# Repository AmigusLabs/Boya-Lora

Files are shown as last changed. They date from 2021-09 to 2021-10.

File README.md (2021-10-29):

# Boia-Lora
### Boia con alimentación solar, para telemetria de temperatura e altuara da ola do lago de As Pontes. Datos enviados por Lora para o seu procesado.

Ano 2021 - Proxecto financiado por Xunta de Galicia

A idea do proxecto é crear unha boia que nos permita coñecer o estado do lago, ben para goce da praia ou ben para os deportes que nel practícanse.

O obxectivo era crear un  instrumento económico e efectivo para xerar os datos, e en última instancia, mellorar a comprensicón deles. Este é o principal obxectivo do proxecto, deseño, rexistro e presentación dos datos.

Os sensores a bordo da boia permítenlle medir: altura das ondas, período das ondas, potencia das ondas, temperatura da auga, temperatura do aire, presión do aire, voltaxe e consumo actual e localización GPS.

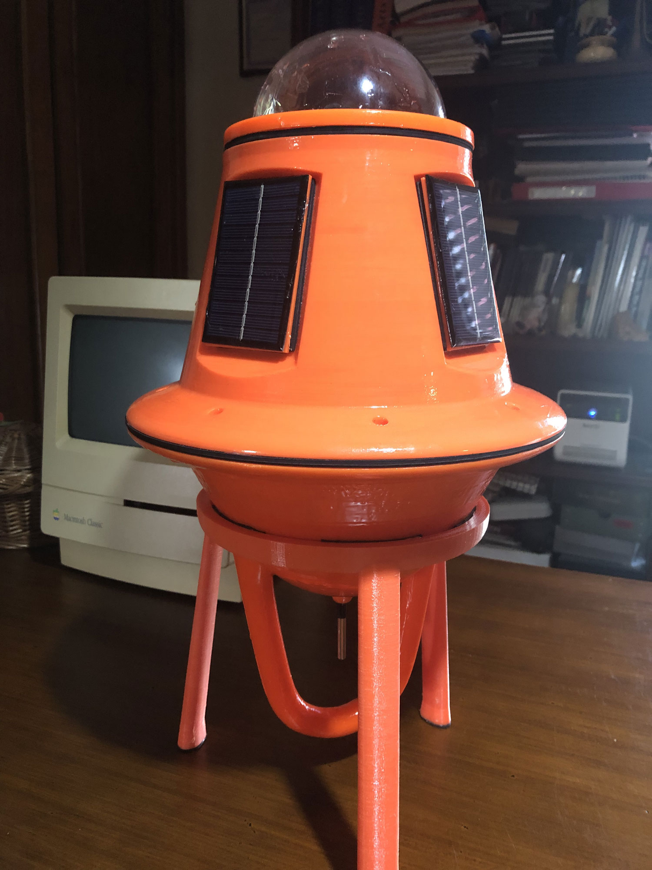
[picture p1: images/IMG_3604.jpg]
Boia lora


## Materiais

Para a construción completa da boia, necesita moitas cousas. Temos a desagregación dos materiais específicos requiridos en está a lista:

- Lilygo T-Beam 868mhzs
- 4 placas solares 90x60mm 6V 100mA
- INA219
- GY-86
- Sensor temperatura DS18B20
- Batería 18650
- PETG para impresión 3d
- GomaEVA
- Conectores PG7
- Regulador MT3608
- JMX-045 domo 4,5" / 114mm

## Estado:
- [ ] Desarrollo web (Rest API)
- [ ] Creación PCBs en KiCad para a electrónica
- [ ] Implementación Lora e envio a TTNv3
- [x] Implementación do software en T-BEAM de temperatua e sensores.
- [x] Implementación control enerxético
- [x] Fabricación 3d
- [x] Corte laser da Goma Eva
- [x] Deseño 2d
- [x] Deseño 3d

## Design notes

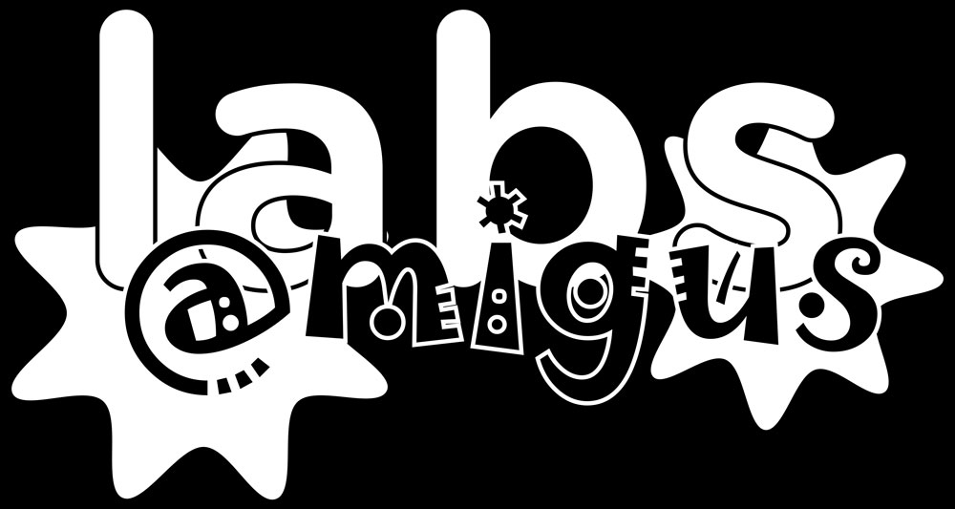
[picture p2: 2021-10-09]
Electronica/Electronica_Kicad_PowerSolar/amigus_labs.jpg

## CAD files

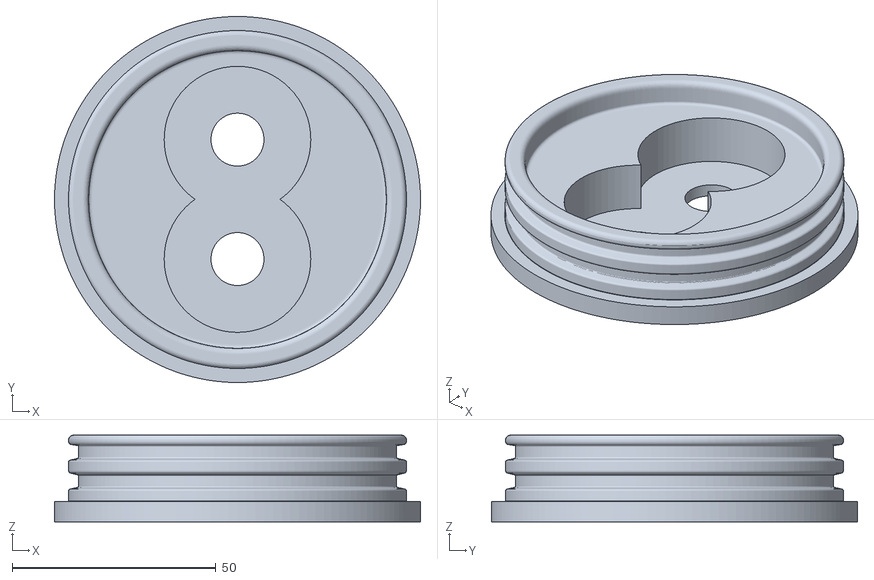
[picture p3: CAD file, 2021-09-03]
STL/tapa_capsula.stl
89.9 x 89.9 x 21.3

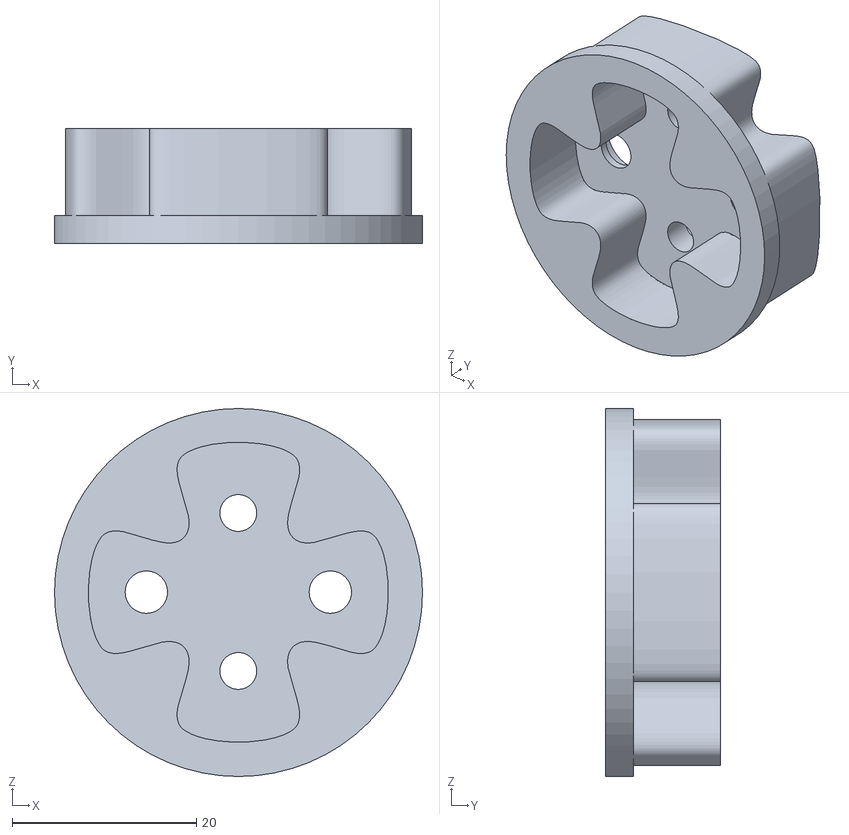
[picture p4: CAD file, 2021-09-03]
STL/soporte_placa_solar2a.stl
40.0 x 12.5 x 40.0

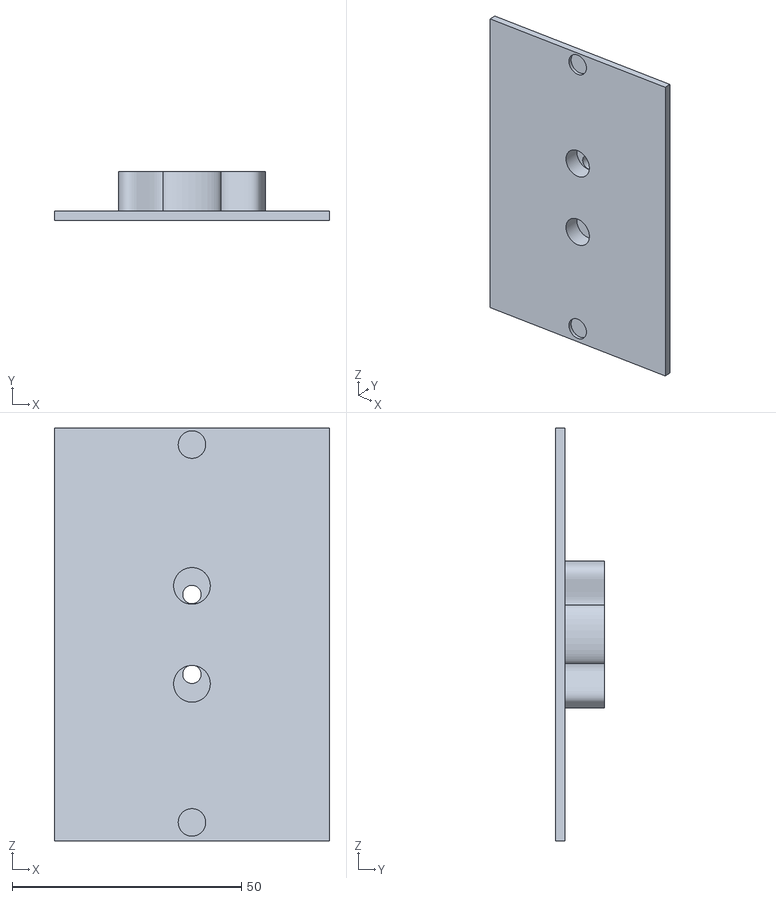
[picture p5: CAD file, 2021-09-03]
STL/soporte_placa_solar2.stl
60.0 x 10.6 x 90.0

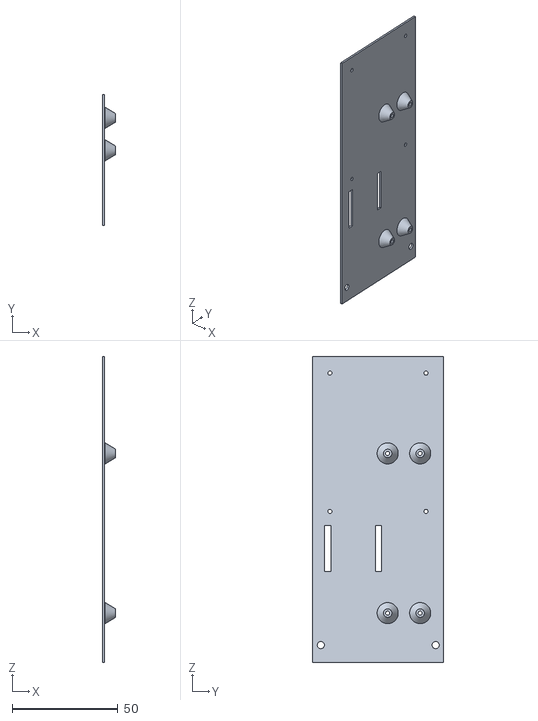
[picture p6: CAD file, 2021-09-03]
STL/soporte_PCBs1.stl
6.33 x 62.0 x 145.0

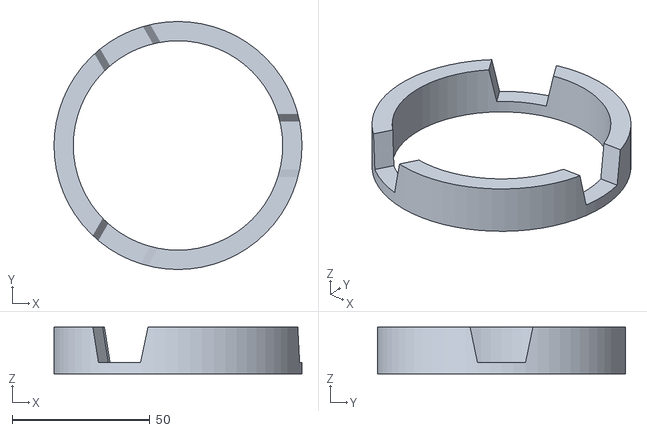
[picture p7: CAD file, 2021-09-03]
STL/soporte_capsula_17mmA.stl
90.0 x 90.0 x 17.0

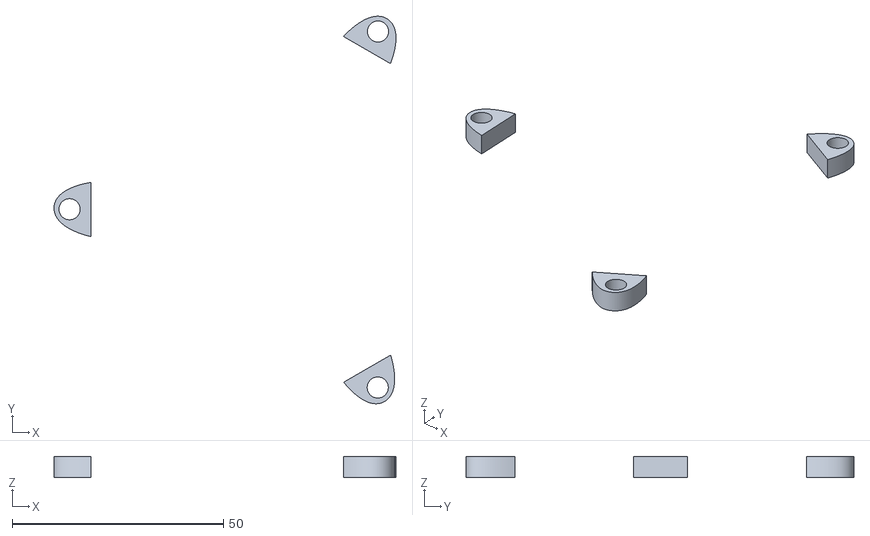
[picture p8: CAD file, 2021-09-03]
STL/tapa_capsula_add.stl
81.0 x 91.8 x 5.00

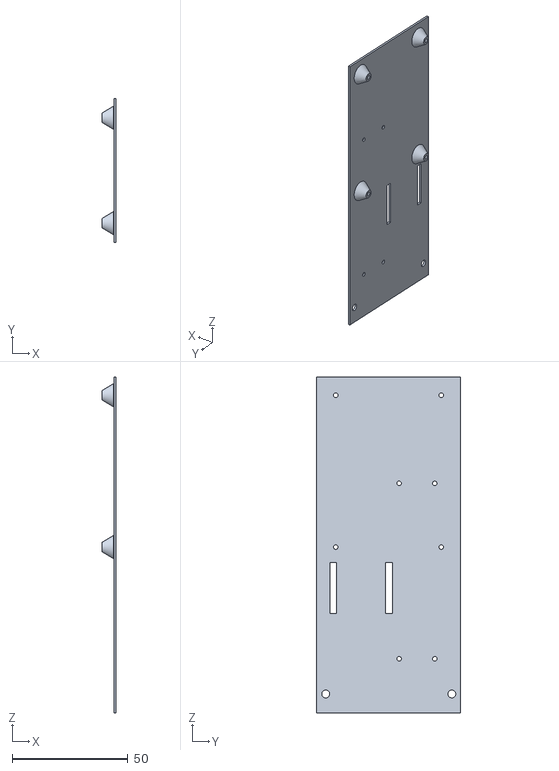
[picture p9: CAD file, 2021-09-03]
STL/soporte_PCBs2.stl
6.13 x 62.0 x 145.0

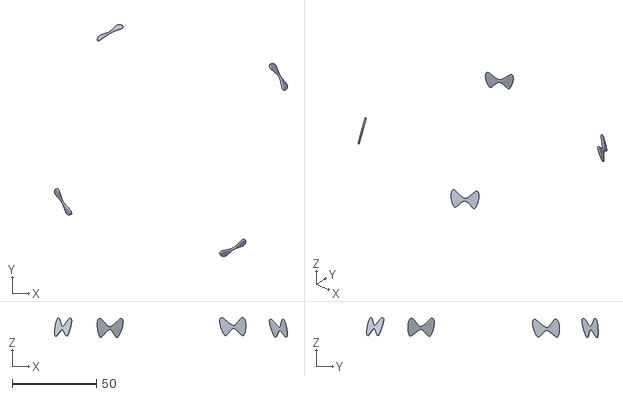
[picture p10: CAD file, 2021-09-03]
STL/Boya_arriba1_soportes.stl
138.6 x 137.9 x 12.0

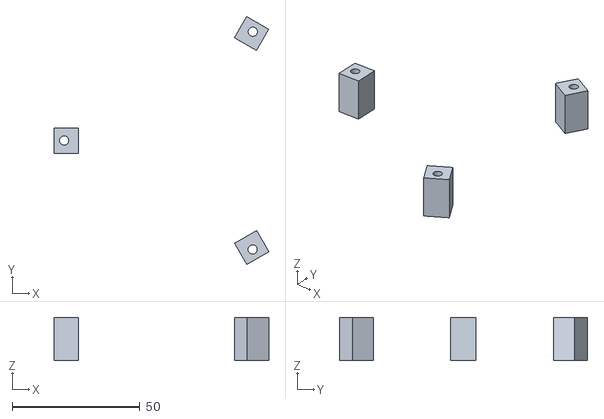
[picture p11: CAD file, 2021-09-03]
STL/soporte_capsula_17mmB.stl
84.1 x 97.1 x 17.0

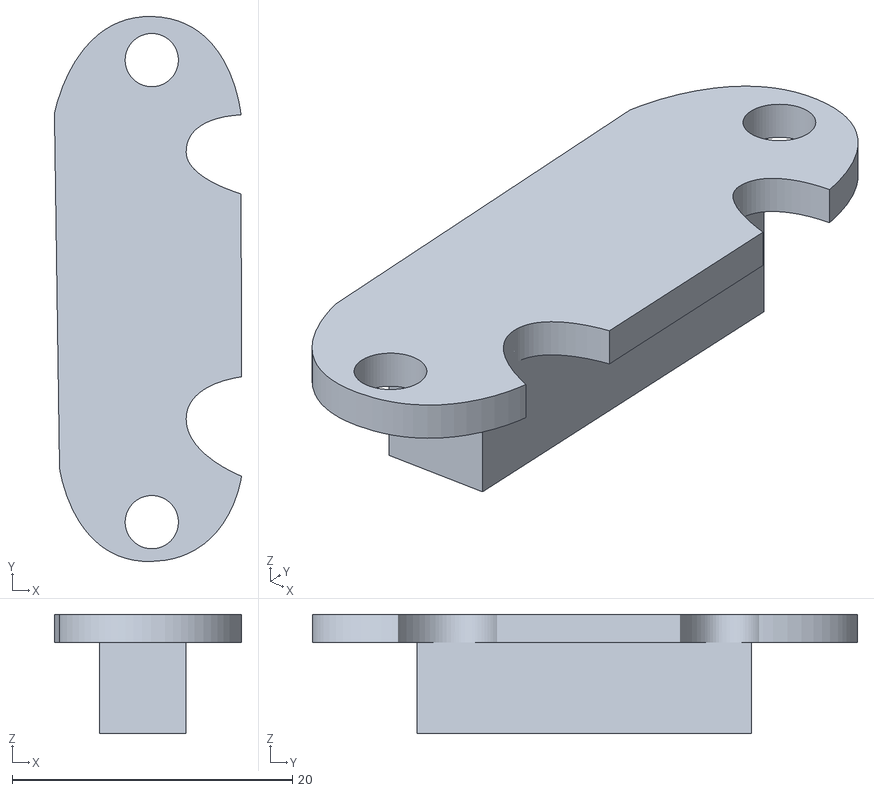
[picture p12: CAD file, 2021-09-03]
STL/Soporte_AntenaGPS.stl
13.4 x 38.9 x 8.51

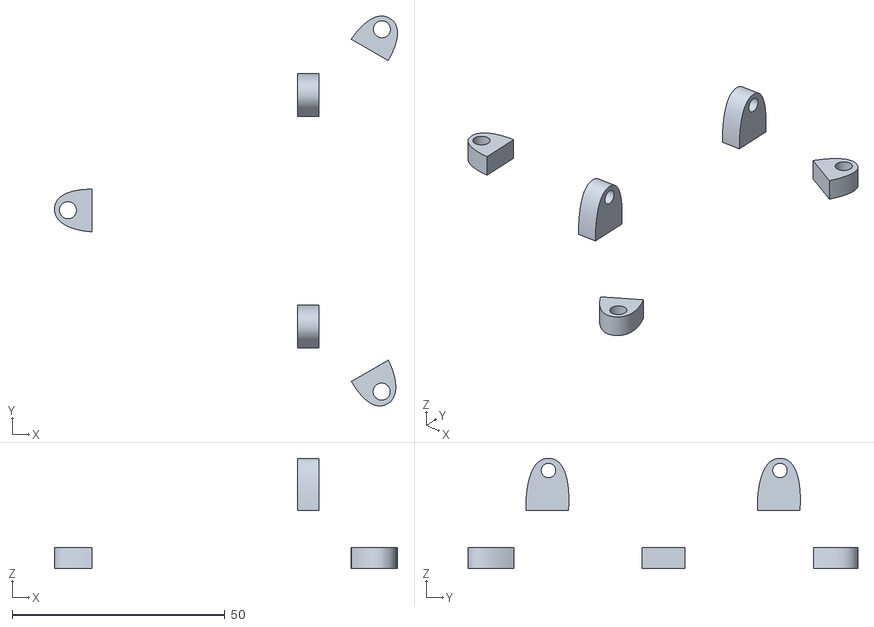
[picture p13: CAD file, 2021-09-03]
STL/tapa_capsula_superior_add.stl
80.7 x 91.7 x 26.0

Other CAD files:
STL/tapa_capsula_superior.stl

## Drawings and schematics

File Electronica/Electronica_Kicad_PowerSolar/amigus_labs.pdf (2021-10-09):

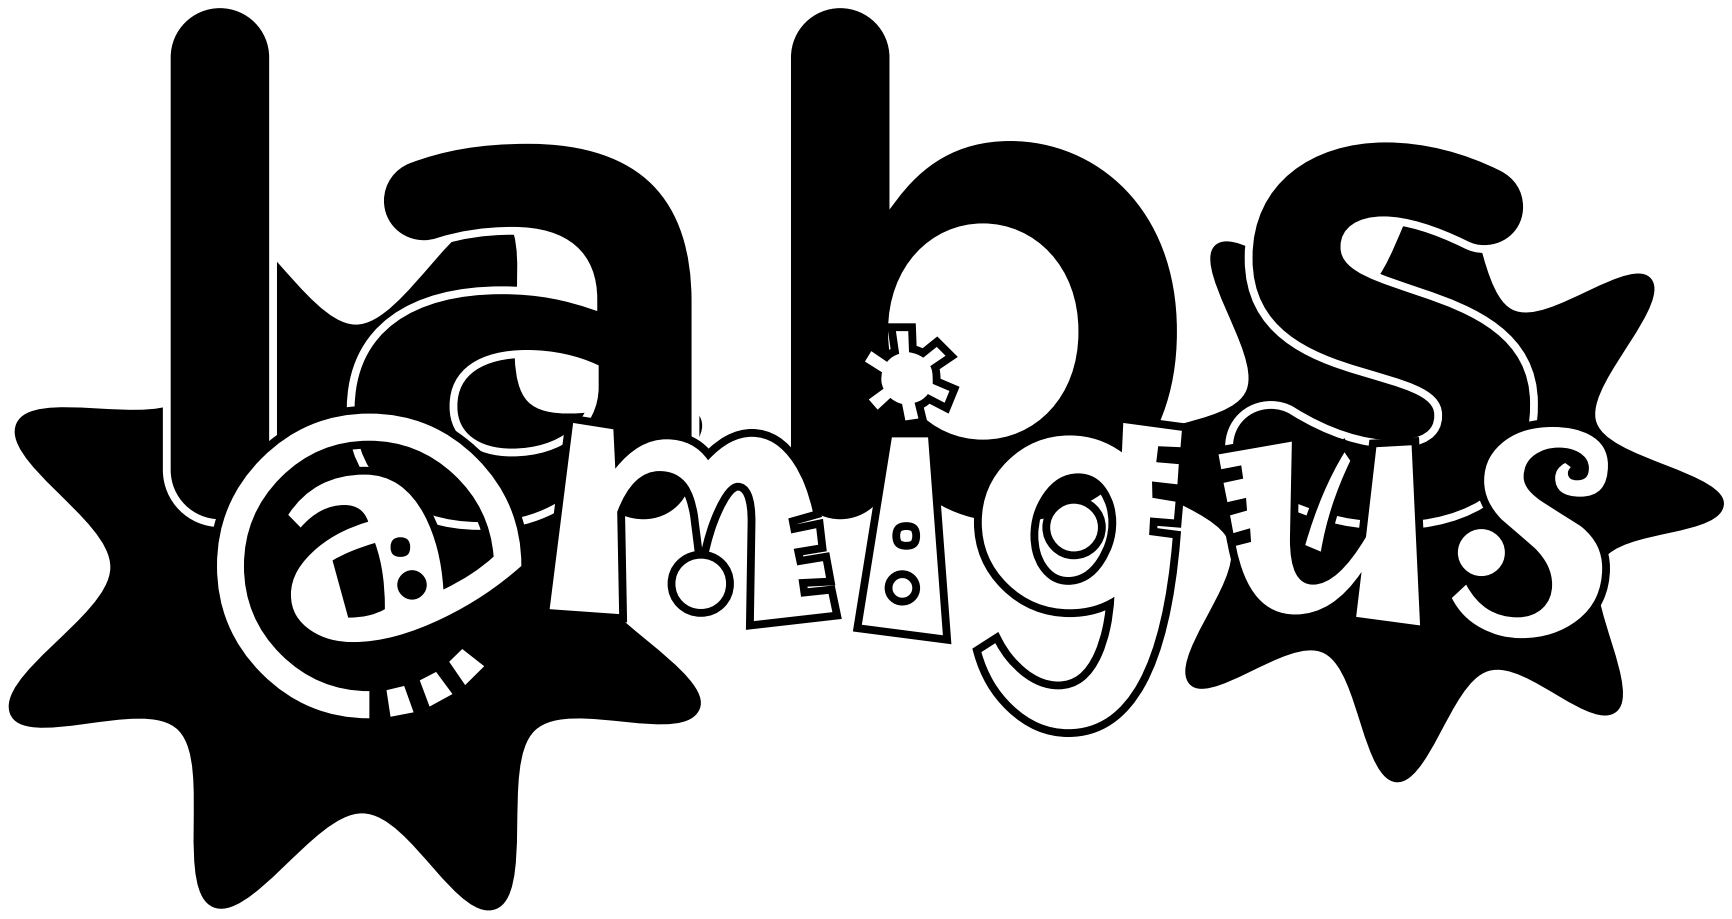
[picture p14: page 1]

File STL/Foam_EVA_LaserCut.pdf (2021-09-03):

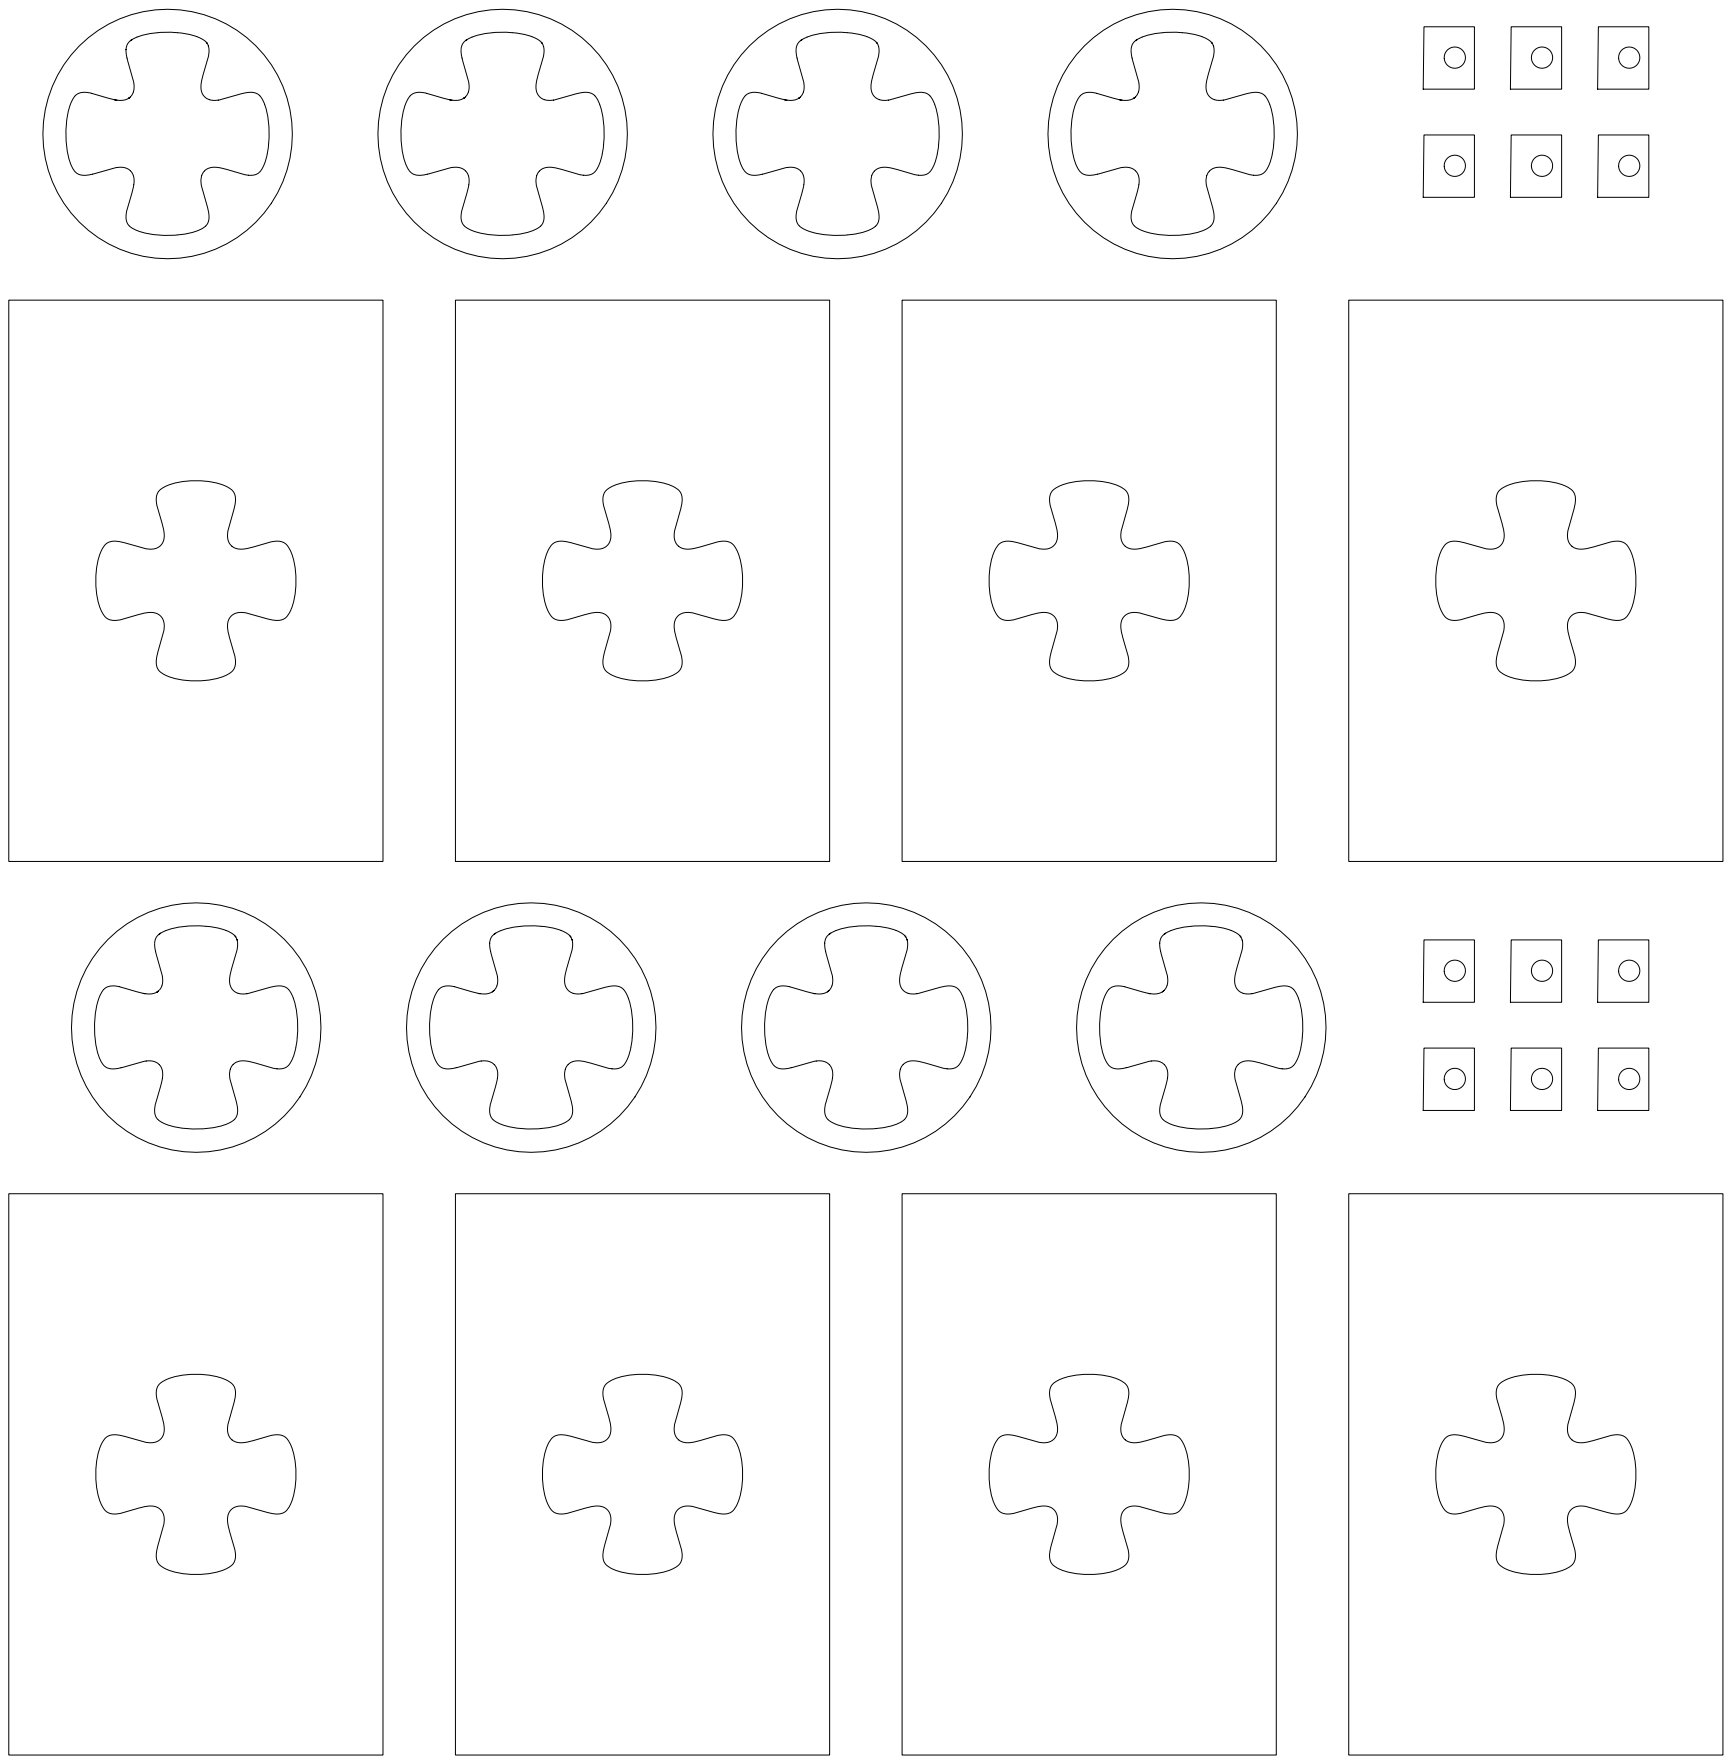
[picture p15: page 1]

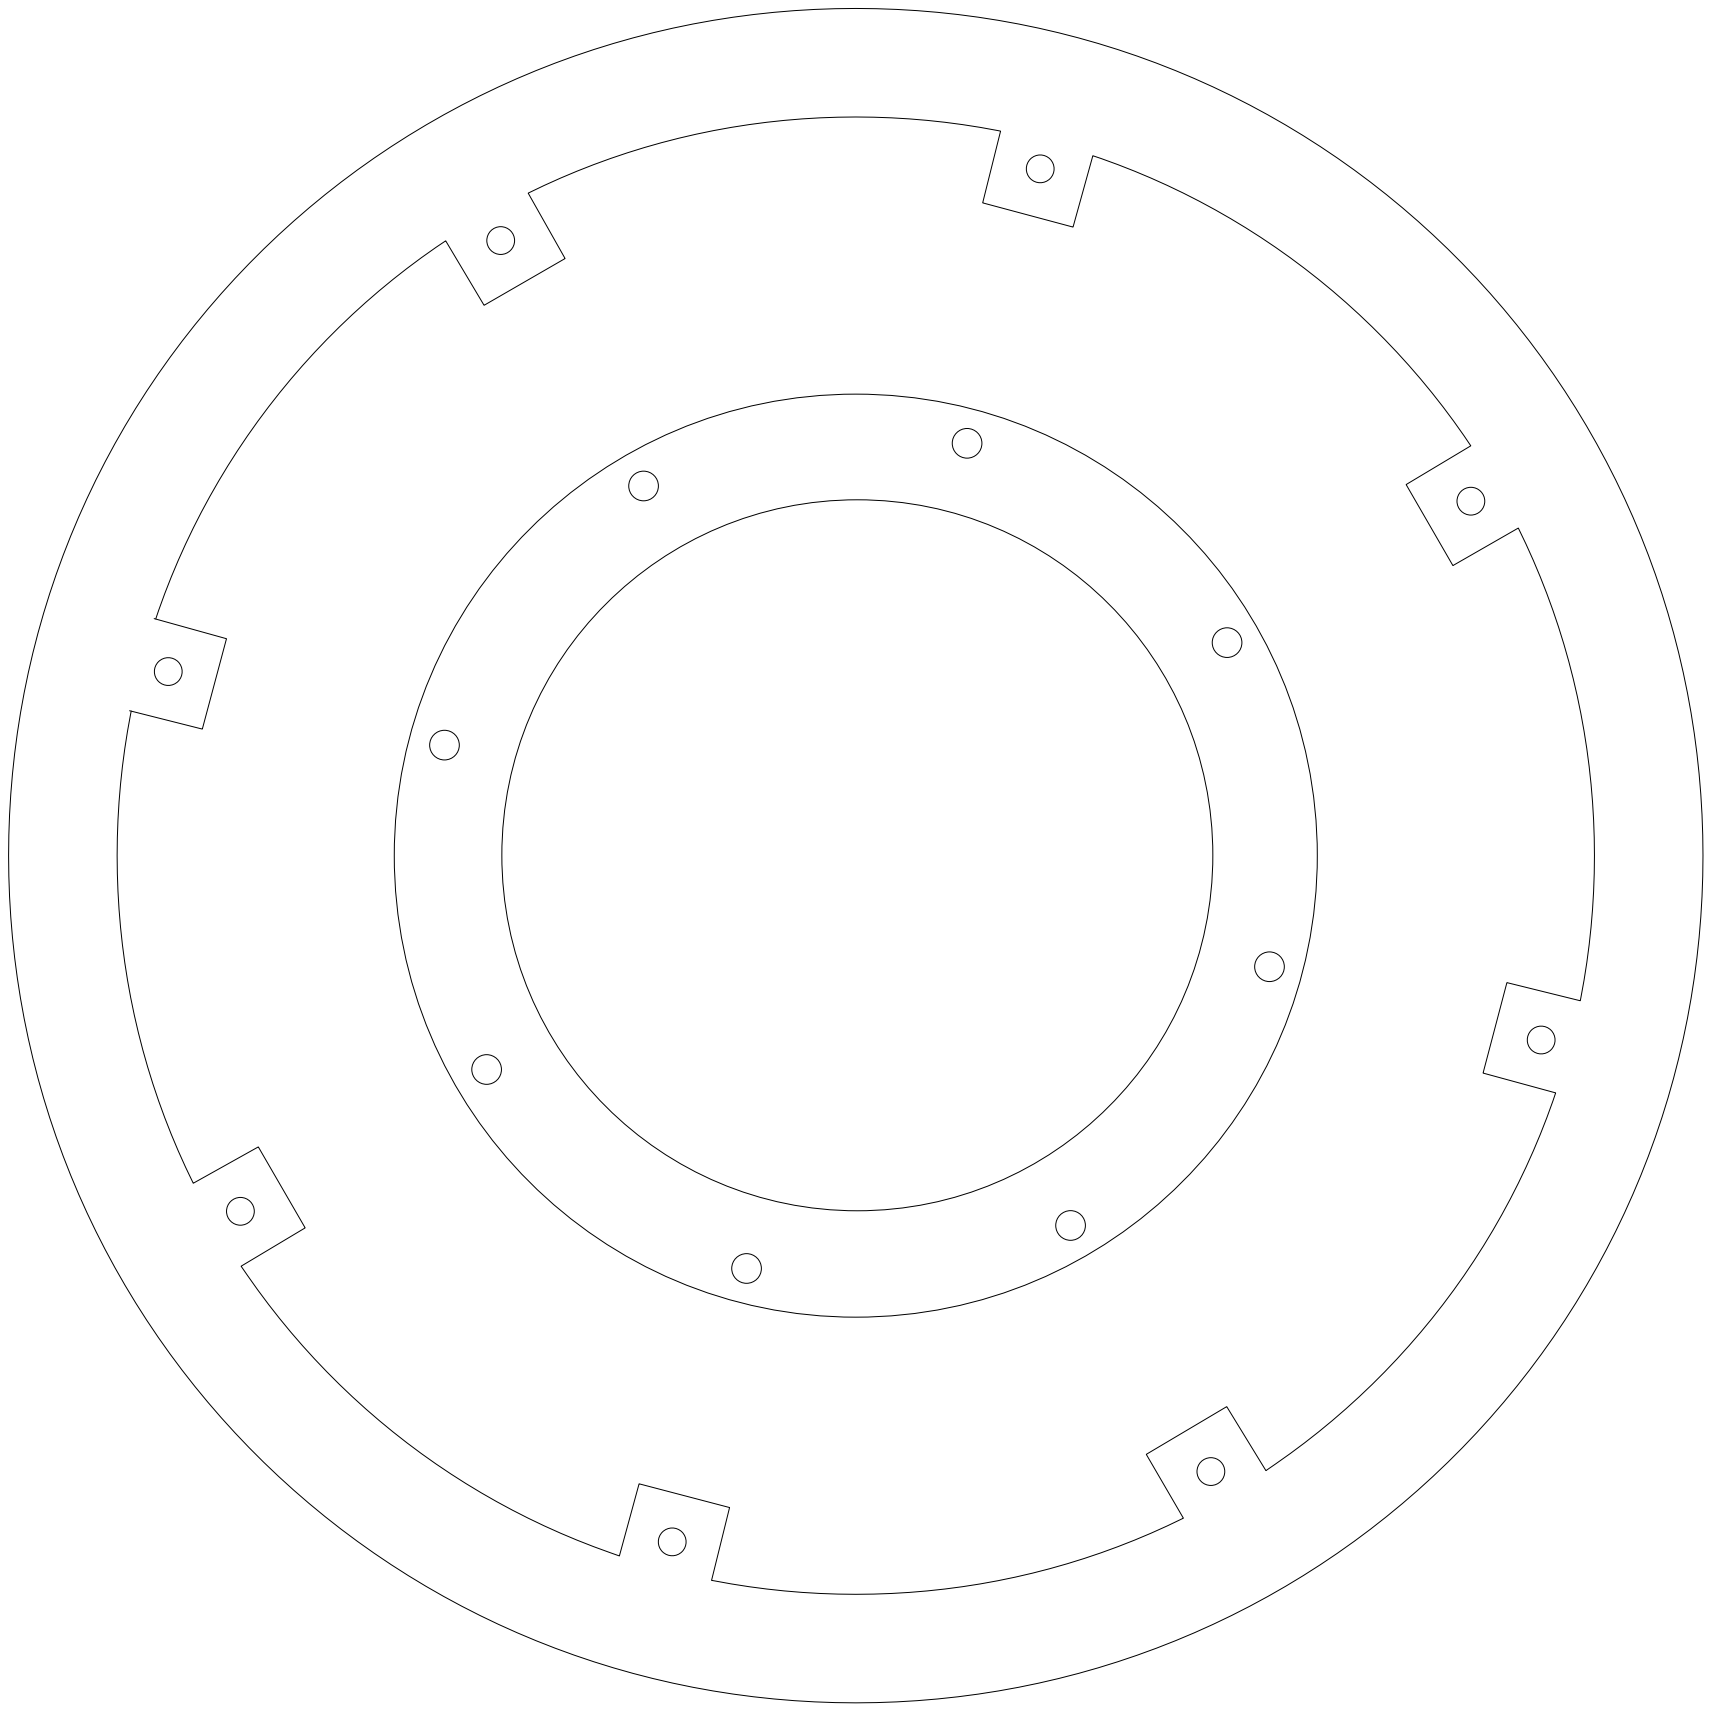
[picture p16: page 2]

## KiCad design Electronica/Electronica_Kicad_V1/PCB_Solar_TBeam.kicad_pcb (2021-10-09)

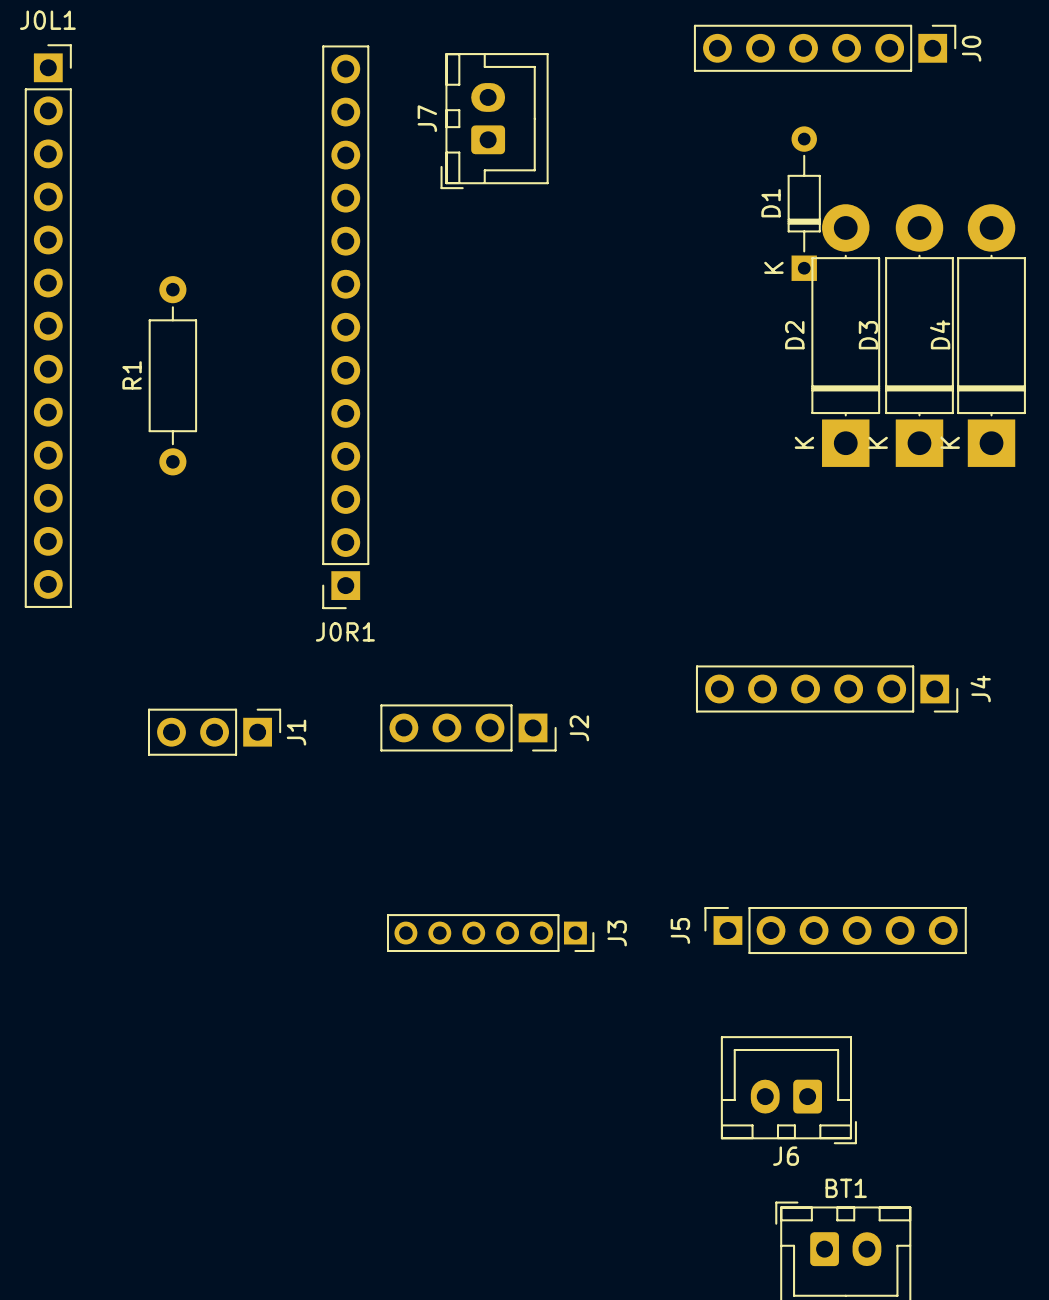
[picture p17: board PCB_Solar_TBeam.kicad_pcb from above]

Board: 2 copper layers, 16 parts (0 on the bottom side), 15 nets, no tracks yet.

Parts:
BT1: Battery; JST_XH_B2B-XH-A_1x02_P2.50mm_Vertical
D1: D; D_DO-34_SOD68_P7.62mm_Horizontal
D2, D3, D4: D; D_5W_P12.70mm_Horizontal
J0: IN Solar Power; PinHeader_1x06_P2.54mm_Vertical
J0L1: TTGO T-beam; PinSocket_1x13_P2.54mm_Vertical
J0R1: Conn_01x13_Female; PinSocket_1x13_P2.54mm_Vertical
J1: Termometro; PinHeader_1x03_P2.54mm_Vertical
J2: GY86; PinSocket_1x04_P2.54mm_Vertical
J3: INA219; PinSocket_1x06_P2.00mm_Vertical
J4, J5: Cargador 03962A; PinSocket_1x06_P2.54mm_Vertical
J6: INA219; JST_XH_B2B-XH-A_1x02_P2.50mm_Vertical
J7: Bat IN 5V; JST_XH_B2B-XH-A_1x02_P2.50mm_Vertical
R1: 4.7K; R_Axial_DIN0207_L6.3mm_D2.5mm_P10.16mm_Horizontal

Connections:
unnamed: BT1.1, J6.1
unnamed: BT1.2, J5.5
unnamed: D1.1, D2.1, D3.1, D4.1, J4.1
unnamed: D1.2, J0.4
unnamed: D2.2, J0.3
unnamed: D3.2, J0.2
unnamed: D4.2, J0.1
unnamed: J0.6, J4.6
unnamed: J0L1.3, J1.1, J2.4, J3.6, R1.2
unnamed: J0L1.4, J2.1, J3.3
unnamed: J0L1.5, J2.2, J3.4
unnamed: J0L1.10, J1.3, R1.1
unnamed: J0R1.12, J1.2, J2.3, J3.5, J7.1
unnamed: J0R1.13, J7.2
unnamed: J5.2, J6.2

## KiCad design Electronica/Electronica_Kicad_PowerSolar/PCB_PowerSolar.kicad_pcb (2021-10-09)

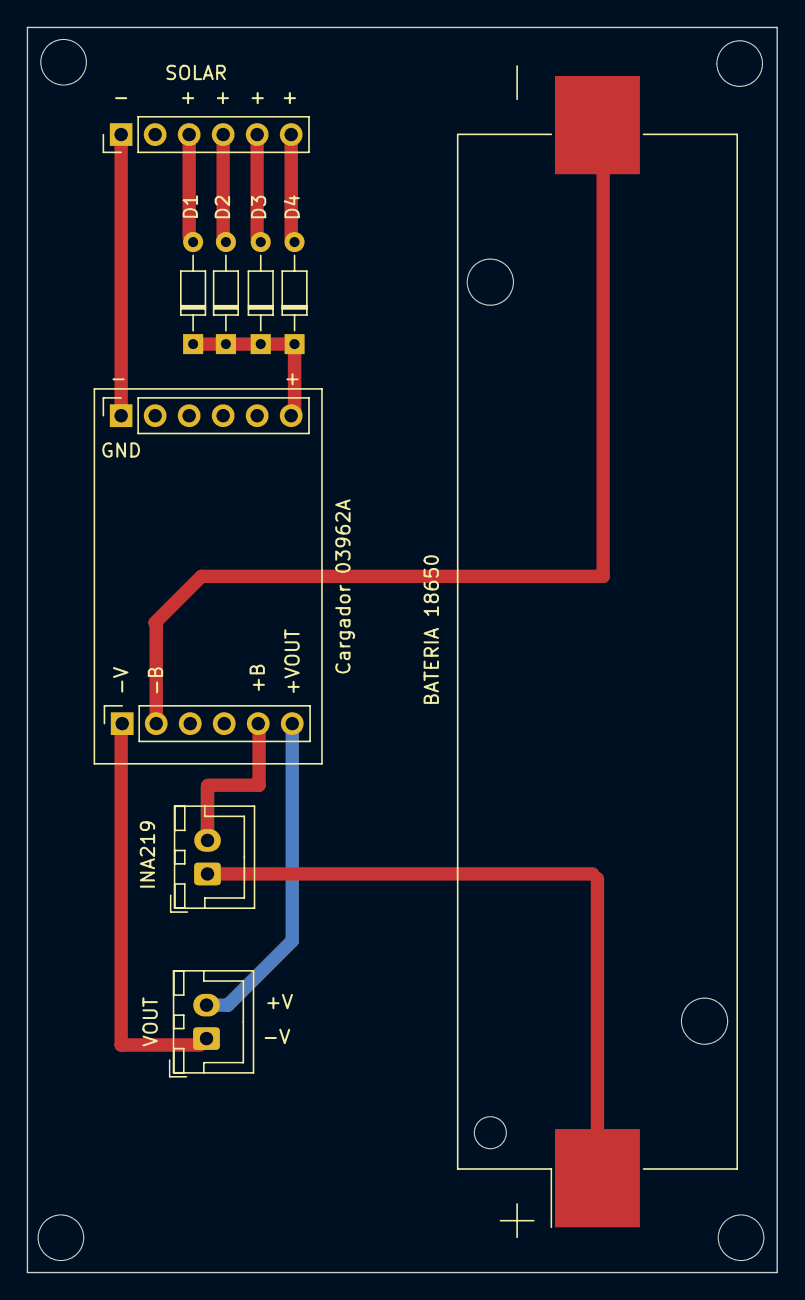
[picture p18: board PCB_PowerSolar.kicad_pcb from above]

Board: 2 copper layers, 56.0 x 93.0 mm, 10 parts (0 on the bottom side), 11 nets.

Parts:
BATERIA 18650: Battery; BatteryHolder_Keystone_1042_1x18650
D1, D2, D3, D4: D; D_DO-34_SOD68_P7.62mm_Horizontal
INA219: INA219; JST_XH_B2B-XH-A_1x02_P2.50mm_Vertical
J1, J2: Cargador 03962A; PinSocket_1x06_P2.54mm_Vertical
SOLAR: IN Solar Power; PinHeader_1x06_P2.54mm_Vertical
VOUT: V-OUT; JST_XH_B2B-XH-A_1x02_P2.50mm_Vertical

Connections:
unnamed: BATERIA 18650.1, INA219.1
unnamed: BATERIA 18650.2, J2.2
unnamed: D1.1, D2.1, D3.1, D4.1, J1.6
unnamed: D1.2, SOLAR.3
unnamed: D2.2, SOLAR.4
unnamed: D3.2, SOLAR.5
unnamed: D4.2, SOLAR.6
unnamed: J1.1, SOLAR.1
unnamed: J2.1, VOUT.1
unnamed: INA219.2, J2.5
unnamed: J2.6, VOUT.2

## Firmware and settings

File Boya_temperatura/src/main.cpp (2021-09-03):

#include <Arduino.h>
#include <OneWire.h>
#include <Wire.h>
#include <DallasTemperature.h>
#include "current.h" //INA219
#include <WiFi.h>
#include <esp_sleep.h>

#include <TinyGPS++.h>
#include <axp20x.h>
#include "I2Cdev.h"
#include "MPU6050.h"
#include <ms5611.h>

// GY86 -- Olas --
MPU6050 mpu;
MS5611 baro;
long pressure;
double altitude, min_height, max_height, wave_height, mid_point, smudge_factor, wave_power;
byte escaped, started;
unsigned long period_start, period_end;
float avg_period = -1;

// GPIO donde el DS18B20 está conectado
const int oneWireBus = 4;
OneWire oneWire(oneWireBus);
DallasTemperature sensors(&oneWire);

// GPS
TinyGPSPlus gps;
HardwareSerial GPS(1);
AXP20X_Class axp;

void setup()
{
  Serial.println("Iniciando");
  Serial.begin(115200);
  // GPS
  Wire.begin(21, 22);
  if (!axp.begin(Wire, AXP192_SLAVE_ADDRESS))
  {
    Serial.println("AXP192 Begin PASS");
  }
  else
  {
    Serial.println("AXP192 Begin FAIL");
  }
  axp.setPowerOutPut(AXP192_LDO2, AXP202_ON);
  axp.setPowerOutPut(AXP192_LDO3, AXP202_ON);
  axp.setPowerOutPut(AXP192_DCDC2, AXP202_ON);
  axp.setPowerOutPut(AXP192_EXTEN, AXP202_ON);
  axp.setPowerOutPut(AXP192_DCDC1, AXP202_ON);
  GPS.begin(9600, SERIAL_8N1, 34, 12); //17-TX 18-RX

  WiFi.mode(WIFI_OFF);
  btStop();

  init_INA219(0);

  if (axp.begin(Wire, AXP192_SLAVE_ADDRESS) == AXP_FAIL)
  {
    Serial.println(F("failed to initialize communication with AXP192"));
  }

  // Encendiendo GPS
  sensors.begin();

  if (axp.setPowerOutPut(AXP192_LDO3, AXP202_ON) == AXP_PASS)
  {
    Serial.println(F("turned ON GPS module"));
  }
  else
  {
    Serial.println(F("failed to turn off GPS module"));
  }

  // GY86 --Olas --
  Wire.begin();
  Serial.println("Initializing I2C devices...");
  mpu.setI2CMasterModeEnabled(false);
  mpu.setI2CBypassEnabled(true);
  mpu.setSleepEnabled(false);
  mpu.initialize();
  Serial.println(mpu.testConnection() ? "MPU6050 connection successful" : "MPU6050 connection failed");
  while (!baro.begin(MS5611_ULTRA_HIGH_RES))
  {
    Serial.println("MS5611 connection unsuccessful, check wiring!");
    delay(500);
  }
}

void loop()
{

  // Temperatura DS18B20
  sensors.requestTemperatures();            //Se envía el comando para leer la temperatura
  float tempC = sensors.getTempCByIndex(0); //Se obtiene la temperatura en ºC
  Serial.print(tempC);
  Serial.println("ºC");


  // INA219
  float Voltaje = get_LoadVolts();
  float Consumo = get_LoadCurrent();
  Serial.print(Voltaje);
  Serial.print("V - ");
  Serial.print(Consumo);
  Serial.println("mA");

  // V y mA placa
  Serial.print(axp.getBattVoltage() / 1000);
  Serial.print("V  APX- ");
  Serial.print(axp.getBattChargeCurrent() - axp.getBattDischargeCurrent());
  Serial.println(" mA");


  unsigned long start_time = millis();
  pressure = baro.readPressure(true);
  altitude = baro.getAltitude(pressure);
  max_height = altitude;
  min_height = altitude;
  //  Espera 15 segundos

  pressure = baro.readPressure(true);
  float raw = pressure;
  float filtro = 8;
  while (millis() - start_time < 15000)
  {

    // pressure = baro.readPressure(true);

    // filtro presion
    raw = baro.readPressure(true);

    pressure = ((filtro - 1) * pressure + raw) / filtro;

    altitude = baro.getAltitude(pressure);

    if (altitude < min_height)
      min_height = altitude;
    if (altitude > max_height)
      max_height = altitude;
  }
  mid_point = (max_height + min_height) / 2.0;
  wave_height = (max_height - mid_point) / 2.0;
  smudge_factor = wave_height * 0.15;
  Serial.print("Altura de la ola m: ");
  Serial.print(wave_height);

  start_time = millis();
  //  Espera 15 segundos
  // pressure = baro.readPressure(true);
  while (millis() - start_time < 15000)
  {

    raw = baro.readPressure(true);
    pressure = ((filtro - 1) * pressure + raw) / filtro;

    altitude = baro.getAltitude(pressure);
    //    si está dentro de un rango del 30% de la altura de la ola desde el punto medio
    //    inicia el temporizador de lo contrario lo detiene
    if (altitude < mid_point + smudge_factor && altitude > mid_point - smudge_factor)
    {
      if (!started)
      {
        period_start = millis();
        started = true;
      }
      else
      {
        if (escaped)
        {
          // if it has started and escaped and is now returning
          period_end = millis();
          started = false;
          escaped = false;
          // if the variable has already been assigned
          // use its previous value and new value to work out avg
          if (avg_period != -1)
          {
            avg_period = (avg_period + (period_end - period_start) * 2) / 2.0;
          }
          // assign it
          else
          {
            avg_period = (period_end - period_start) * 2;
          }
        }
      }
    }
    else
    {
      escaped = true;
    }
  }
  Serial.print("  Periodo s: ");
  Serial.print(avg_period / 1000);
  wave_power = (0.5 * wave_height * wave_height * avg_period / 1000);
  Serial.print("  Potencia de la ola kW/m: ");
  Serial.println(wave_power);


  Serial.print("Latitude  : ");
  Serial.println(gps.location.lat(), 5);
  Serial.print("Longitude : ");
  Serial.println(gps.location.lng(), 4);
  Serial.print("Satellites: ");
  Serial.println(gps.satellites.value());
  Serial.print("Altitude  : ");
  Serial.print(gps.altitude.feet() / 3.2808);
  Serial.println("M");
  Serial.print(F("Date      : "));
  Serial.print(gps.date.month());
  Serial.print(F("/"));
  Serial.print(gps.date.day());
  Serial.print(F("/"));
  Serial.println(gps.date.year());
  Serial.print("Time      : ");
  Serial.print(gps.time.hour());
  Serial.print(":");
  Serial.print(gps.time.minute());
  Serial.print(":");
  Serial.println(gps.time.second());
  Serial.print("Speed     : ");
  Serial.println(gps.speed.kmph());
  Serial.println("**********************");


  delay(10000);

  // Apaga GPS
  Serial.println("GPS_OFF");

  if (axp.setPowerOutPut(AXP192_LDO3, AXP202_OFF) == AXP_PASS)
  {
    Serial.println(F("Apaga el moódulo GPS"));
  }
  else
  {
    Serial.println(F("Ha falaldo apagar el GPS"));
  }

  Serial.print(Voltaje);
  Serial.print("V - ");
  Serial.print(Consumo);
  Serial.println("mA");

  // V y mA placa
  Serial.print(axp.getBattVoltage() / 1000);
  Serial.print("V APX - ");
  Serial.print(axp.getBattChargeCurrent() - axp.getBattDischargeCurrent());
  Serial.println(" mA");


  delay(10000);

  // Empieza a dormir
  Serial.println("Deep Sleep");

Serial.print(Voltaje);
  Serial.print("V - ");
  Serial.print(Consumo);
  Serial.println("mA");

  // V y mA placa
  Serial.print(axp.getBattVoltage() / 1000);
  Serial.print("V APX - ");
  Serial.print(axp.getBattChargeCurrent() - axp.getBattDischargeCurrent());
  Serial.println(" mA");
  
  esp_sleep_enable_timer_wakeup(30 * 1000 * 1000);
  esp_deep_sleep_start();
}

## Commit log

2021-09-03 New to GitHub
    Add to GitHub
    [Boya_arriba1_soportes.stl, Soporte_AntenaGPS.stl, placa_solar1.stl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]
2021-10-09 KiCad files
    En desarrollo
    [PCB_PowerSolar.kicad_pcb, PCB_PowerSolar.sch, PCB_Solar_TBeam.kicad_pcb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]
